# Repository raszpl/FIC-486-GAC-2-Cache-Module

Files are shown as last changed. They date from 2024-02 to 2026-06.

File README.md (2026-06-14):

# FIC-486-GAC-2 Cache Module reproduction
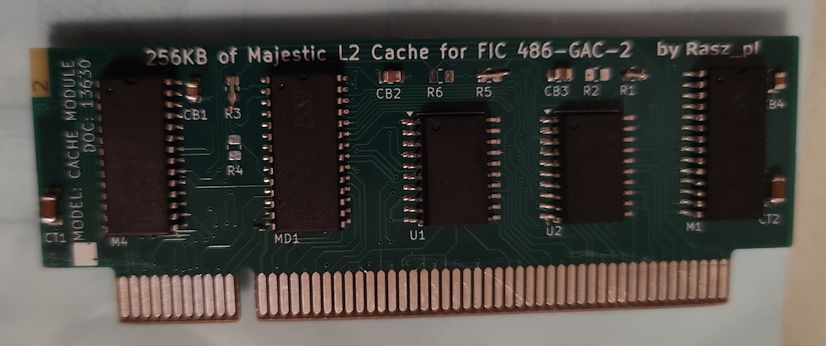
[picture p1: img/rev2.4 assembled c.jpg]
[](https://raw.githubusercontent.com/raszpl/FIC-486-GAC-2-Cache-Module/main/img/rev2.4%20assembled%20c.jpg)

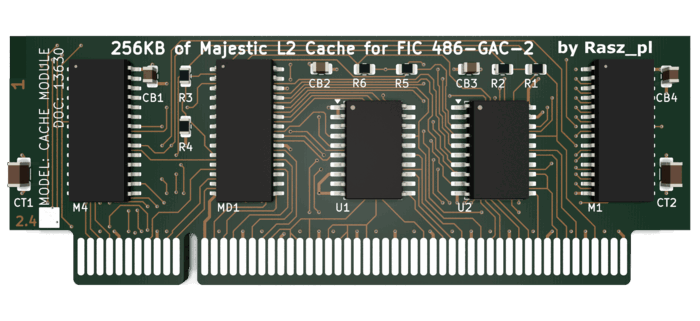
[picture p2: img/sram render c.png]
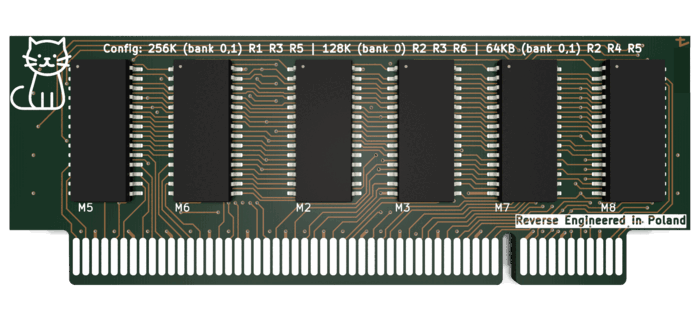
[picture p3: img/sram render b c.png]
[](https://raw.githubusercontent.com/raszpl/FIC-486-GAC-2-Cache-Module/main/img/sram%20render.png) [](https://raw.githubusercontent.com/raszpl/FIC-486-GAC-2-Cache-Module/main/img/sram%20render%20b.png)

Reverse Engineered non standard 256K L2 Cache Module for use in:

- AT&T GLOBALYST 510 = NCR 3228 = [FIC 486-GAC-2](https://theretroweb.com/motherboards/s/fic-486-gac-2)
- AT&T GLOBALYST 515 = NCR 3232 = [FIC 486-GAC-2](https://theretroweb.com/motherboards/s/fic-486-gac-2)

Potentially also:
- AT&T Globalyst 520 = NCR 3238 = [FIC 486-PAK-3](https://www.vogons.org/viewtopic.php?t=80951) needs confirmation
- AT&T Globalyst 530 = NCR 3338 = [FIC 486-PAK-3](https://www.vogons.org/viewtopic.php?t=80951) needs confirmation
- NCR 3231
- AT&T Globalyst 525 = NCR 3253

**Incompatible** platforms also reusing VLB slot for Cache:
- AT&T
  - [Globalyst 550 = NCR 3246](https://theretroweb.com/motherboards/s/atandt,-inc.-at-and-t,-inc.-globalyst-550-c) 
  - Globalyst 575 = NCR 3347 both use [517-0002811](https://raw.githubusercontent.com/raszpl/FIC-486-GAC-2-Cache-Module/refs/heads/main/not%20compatible%20proprietary%20vlb%20cache%20modules/ATT-Globalyst_550_575.jpg)
- Compaq
  - [ProLinea 4/66 (164560-001)](https://theretroweb.com/motherboards/s/compaq-prolinea-4-66)
  - [ProLinea MT/833CDS/850/850CDS/860CDS/866 (197023-001)](https://theretroweb.com/motherboards/s/compaq-prolinea-mt)
  - [Presario 700-900 series (171009-001)](https://theretroweb.com/motherboards/s/compaq-presario-700-900-series-486) all three use 128KB 197005-001 (aka 003454-001, 003670-001, 197050-001) [front](https://raw.githubusercontent.com/raszpl/FIC-486-GAC-2-Cache-Module/refs/heads/main/not%20compatible%20proprietary%20vlb%20cache%20modules/Compaq%20197005-001.jpg) [back](https://raw.githubusercontent.com/raszpl/FIC-486-GAC-2-Cache-Module/refs/heads/main/not%20compatible%20proprietary%20vlb%20cache%20modules/Compaq%20197005-001%20back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) [in slot](https://raw.githubusercontent.com/raszpl/FIC-486-GAC-2-Cache-Module/refs/heads/main/not%20compatible%20proprietary%20vlb%20cache%20modules/Compaq%20197005-001%20in%2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) 100% working DIY **[256KB/1MB Replacement](https://github.com/wichers/Compaq-Cache-Module-197005-001)** by [sander wichers](https://www.vogons.org/viewtopic.php?t=102242) inspired by this project :)
  - [Prosignia VS](https://www.digitaldungeon.be/digitaldungeon/computer/compaq/prosignia-vs_01/prosignia-vs_01.html) uses Sony CXK784862Q-33 based 256KB 194380-001 [front](/not%20compatible%20proprietary%20vlb%20cache%20modules/Compaq%20194380-001.jpg?raw=true) [back](https://raw.githubusercontent.com/raszpl/FIC-486-GAC-2-Cache-Module/refs/heads/main/not%20compatible%20proprietary%20vlb%20cache%20modules/Compaq%20194380-001%20back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)
  - [DESKPRO XE 486](https://theretroweb.com/motherboards/s/compaq-deskpro-xe-486) uses Sony CXK784862Q-33 based 256KB Kingston KTC-4358 [front](https://raw.githubusercontent.com/raszpl/FIC-486-GAC-2-Cache-Module/refs/heads/main/not%20compatible%20proprietary%20vlb%20cache%20modules/Kingston%20KTC-4358.jpg) [in slot](https://raw.githubusercontent.com/raszpl/FIC-486-GAC-2-Cache-Module/refs/heads/main/not%20compatible%20proprietary%20vlb%20cache%20modules/Kingston%20KTC-4358%20insi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). Maybe 194380-001 compatible?
  - [Deskpro/i Family 3](https://theretroweb.com/motherboards/s/compaq-deskpro-i-family-3-25i-rev-1-p-n-002) uses Intel A82485-33 based 64KB 141345-001 (002581)
  - [Deskpro/i Family 4](https://theretroweb.com/motherboards/s/compaq-deskpro-i-family-4-25is-rev-3-p-n-00) uses Intel A82485-33 based 64KB 141477-001 (002754) [front](https://raw.githubusercontent.com/raszpl/FIC-486-GAC-2-Cache-Module/refs/heads/main/not%20compatible%20proprietary%20vlb%20cache%20modules/Compaq%20002754-001.jpg) [back](https://raw.githubusercontent.com/raszpl/FIC-486-GAC-2-Cache-Module/refs/heads/main/not%20compatible%20proprietary%20vlb%20cache%20modules/Compaq%20002754-001%20back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)
- [HP Vectra VE 4](https://theretroweb.com/motherboards/s/hp-vectra-ve-4-xxx-d3501) uses 256KB HP D2465A/IDT 7MP6193 [front](https://raw.githubusercontent.com/raszpl/FIC-486-GAC-2-Cache-Module/refs/heads/main/not%20compatible%20proprietary%20vlb%20cache%20modules/HP%20Vectra%20VE%204%20256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) [back](https://raw.githubusercontent.com/raszpl/FIC-486-GAC-2-Cache-Module/refs/heads/main/not%20compatible%20proprietary%20vlb%20cache%20modules/HP%20Vectra%20VE%204%20256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)
- [HPE NetServer LC 5/166 (D4861AR)](https://theretroweb.com/motherboards/s/hp-netserver-lc) uses 256KB HP D3322A/IDT 7MP6152 (HP 0960-0899) [front](https://raw.githubusercontent.com/raszpl/FIC-486-GAC-2-Cache-Module/refs/heads/main/not%20compatible%20proprietary%20vlb%20cache%20modules/7MP6152.jpg)
- [Olivetti M4 454 S](https://theretroweb.com/motherboards/s/olivetti-m4-4x4) uses 128KB CYM9236 and 256KB CYM9237PB [front](https://raw.githubusercontent.com/raszpl/FIC-486-GAC-2-Cache-Module/refs/heads/main/not%20compatible%20proprietary%20vlb%20cache%20modules/CYM9236.jpg) [back](https://raw.githubusercontent.com/raszpl/FIC-486-GAC-2-Cache-Module/refs/heads/main/not%20compatible%20proprietary%20vlb%20cache%20modules/CYM9236%20back.jpg) [with slot](https://raw.githubusercontent.com/raszpl/FIC-486-GAC-2-Cache-Module/refs/heads/main/not%20compatible%20proprietary%20vlb%20cache%20modules/CYM9236%20and%20slot.jpg)
- [Siemens Nixdorf FD200 D882](https://theretroweb.com/motherboards/s/siemens-nixdorf-system-board-d882) uses 256KB CYM9252PB [front](https://raw.githubusercontent.com/raszpl/FIC-486-GAC-2-Cache-Module/refs/heads/main/not%20compatible%20proprietary%20vlb%20cache%20modules/Siemens%20Nixdorf%20FD200%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) [back](https://raw.githubusercontent.com/raszpl/FIC-486-GAC-2-Cache-Module/refs/heads/main/not%20compatible%20proprietary%20vlb%20cache%20modules/Siemens%20Nixdorf%20FD200%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) and unknown 128KB one.
## Resources
Pictures of the original "DOC: 13630" "ASSY: 008-0078204 A" Cache module:

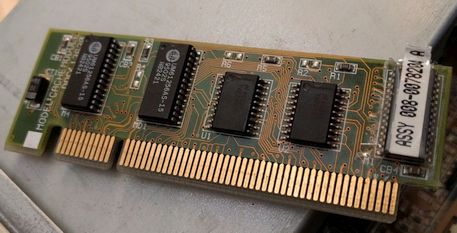
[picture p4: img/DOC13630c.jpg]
rev 2 [front ](https://raw.githubusercontent.com/raszpl/FIC-486-GAC-2-Cache-Module/main/img/DOC13630.jpg)

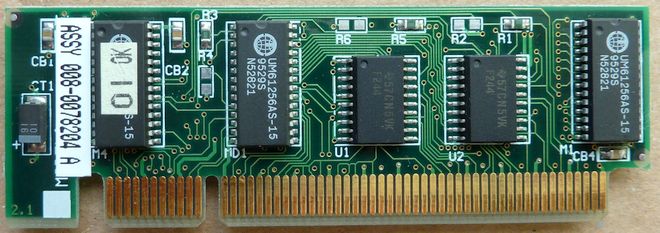
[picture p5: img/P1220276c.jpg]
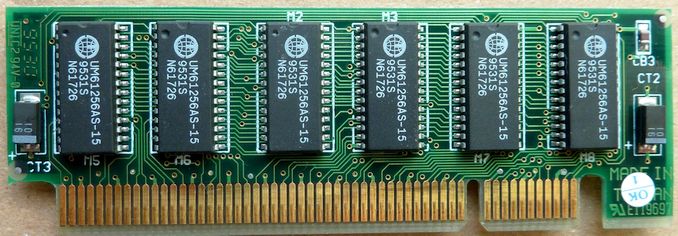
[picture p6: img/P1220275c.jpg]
rev 2.1 [front ](https://raw.githubusercontent.com/raszpl/FIC-486-GAC-2-Cache-Module/main/img/P1220276.JPG), [back ](https://raw.githubusercontent.com/raszpl/FIC-486-GAC-2-Cache-Module/main/img/P1220275.JPG)

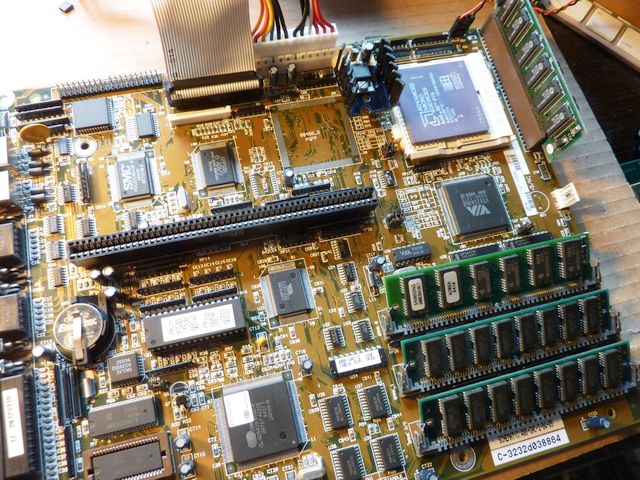
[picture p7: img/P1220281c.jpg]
[plugged into FIC 486-GAC-2](https://raw.githubusercontent.com/raszpl/FIC-486-GAC-2-Cache-Module/main/img/P1220281.JPG)

-----
Vogons [FIC 486-GAC-2 and proprietary cache module](https://www.vogons.org/viewtopic.php?f=46&t=94550) thread:
>majestyk: "FIC sold two different versions with different pinouts (and the same "VLB"-socket). Only the one in the pictures works on a 486-GAC2 and a few other FIC mainboards."

This project was only possible with help provided by majestyk - owner of this very rare Cache module, and RockstarRunner - FIC 486-GAC-2 owner looking for said Cache module. Huge thanks for taking time to capture high resolution pictures and validating progress with measurements.

[UMC UM61256A 32K x 8 Static RAM datasheet](/doc/UMC_UM61256A.pdf)

[VESA VLB slot pinout](/doc/VLB_pins.png) [VESA VLB slot dimensions](/doc/vlb-edge-conn.png)

## Status

100%. Manufactured and tested. Preliminary design took 8 days. Fixes after assembling first prototype 2 days.

## Progress report
4/19/2024: Rev 2.4 assembled by swapping components from Rev 2.2. CACHECHK screenshot.

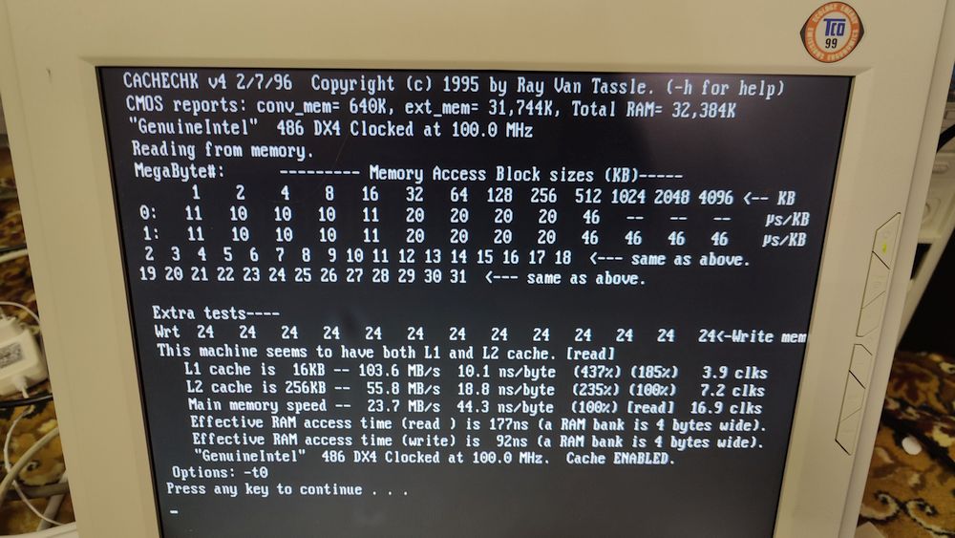
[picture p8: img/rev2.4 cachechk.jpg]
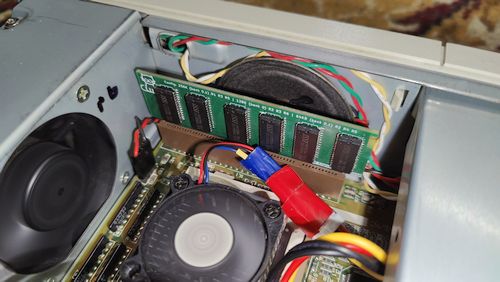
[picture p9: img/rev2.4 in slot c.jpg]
[](https://raw.githubusercontent.com/raszpl/FIC-486-GAC-2-Cache-Module/main/img/rev2.4%20assembled.jpg) [](https://raw.githubusercontent.com/raszpl/FIC-486-GAC-2-Cache-Module/main/img/rev2.4%20cachechk.jpg) [](https://raw.githubusercontent.com/raszpl/FIC-486-GAC-2-Cache-Module/main/img/rev2.4%20in%20slot.jpg)

4/15/2024: Rev 2.4 'Pcbs turned up! We have edge connectors this time 😆'

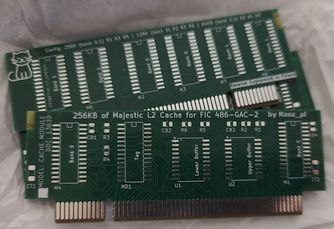
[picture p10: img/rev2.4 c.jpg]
[](https://raw.githubusercontent.com/raszpl/FIC-486-GAC-2-Cache-Module/main/img/rev2.4.jpg)

3/23/2024: [Final Rev 2.4](https://raw.githubusercontent.com/raszpl/FIC-486-GAC-2-Cache-Module/main/img/FIC%20486-GAC-2%20cache%20Final%20rev2.4.png). Reworked SRAM footprint for easier hand soldering, slightly optimized capacitor placement.

2/29/2024: [Final Rev 2.3](https://raw.githubusercontent.com/raszpl/FIC-486-GAC-2-Cache-Module/main/img/FIC%20486-GAC-2%20cache%20Final%20rev2.3.png). Slightly thicker tracks and silkscreen text, additional clearance work. Shrank from initial prototype, should be almost equal height of original. Height when inserted 26.3mm, height including slot 33.6mm. 

2/28/2024: Prototypes assembled after sanding off soldermask from edge slot contacts, didnt work at first try. Turns out I swapped few power/ground pins in the connector resulting in dead short. Great sleuthing by Miisalo uncovered this mishap, after cutting bad connections we have sucessfull boot.

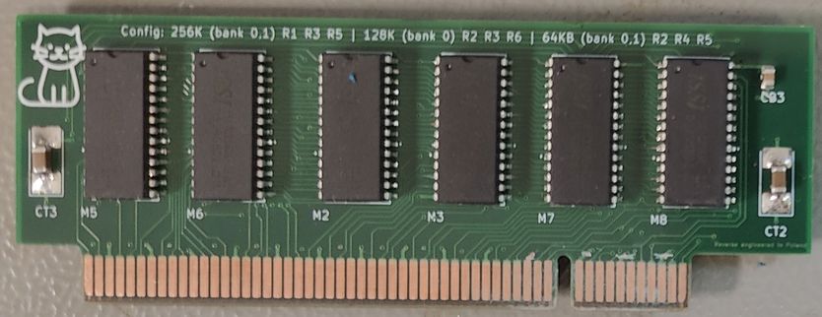
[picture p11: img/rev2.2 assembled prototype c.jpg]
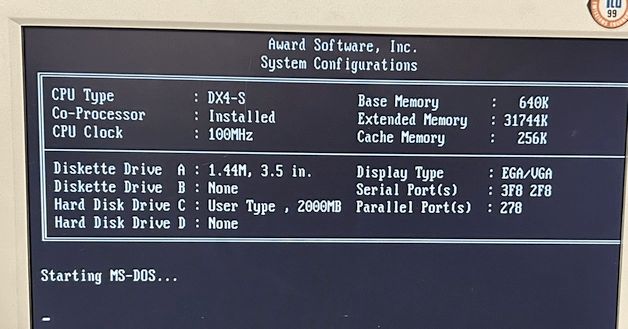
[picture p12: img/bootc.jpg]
[](https://raw.githubusercontent.com/raszpl/FIC-486-GAC-2-Cache-Module/main/img/rev2.2%20assembled%20prototype.jpg) [](https://raw.githubusercontent.com/raszpl/FIC-486-GAC-2-Cache-Module/main/img/boot.jpg)

2/27/2024: Prototypes arrived. Who can spot the problem?

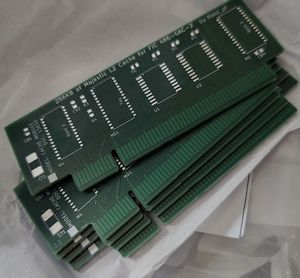
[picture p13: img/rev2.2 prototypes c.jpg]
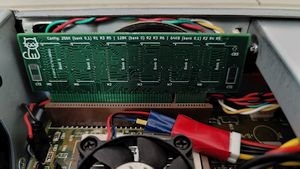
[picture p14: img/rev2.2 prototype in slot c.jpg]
[](https://raw.githubusercontent.com/raszpl/FIC-486-GAC-2-Cache-Module/main/img/rev2.2%20prototypes.jpg) [](https://raw.githubusercontent.com/raszpl/FIC-486-GAC-2-Cache-Module/main/img/rev2.2%20prototype%20in%20slot.jpg)

Will require some finessing with sandpaper to uncover edge slot pads :)

2/11/2024: [99% done](https://raw.githubusercontent.com/raszpl/FIC-486-GAC-2-Cache-Module/main/img/FIC%20486-GAC-2%20cache%20coast%20VIP%2099%25.png), ERC&DRC 0 errors 0 warnings. Footprints should be correct now. Gerbers sent for manufacturing.

2/8/2024: [95% there](https://raw.githubusercontent.com/raszpl/FIC-486-GAC-2-Cache-Module/main/img/FIC%20486-GAC-2%20cache%20coast%20VIP%2095%25.png), 0 errors, 7 Warnings. 5 connections missing, 11 guesses and assumptions on U1 U2 and some more on common lines.

2/6/2024: [90% there](https://raw.githubusercontent.com/raszpl/FIC-486-GAC-2-Cache-Module/main/img/FIC%20486-GAC-2%20cache%20coast%20VIP%2090%25.png), 0 errors 18 warnings. Just a couple tracks left.

2/5/2024: [80% there](https://raw.githubusercontent.com/raszpl/FIC-486-GAC-2-Cache-Module/main/img/FIC%20486-GAC-2%20cache%20coast%20VIP%2080%25.png), 0 drc errors, 62 violations. Still bad footprints and I havent gotten around to fixing power/ground pins. Whats left is figuring LS244 address buffering mapping, TAG ram address and output pins to edge mapping, WE/CE/OE mapping to edge.

2/4/2024: Very VIP, only about 50% there at the moment.

02/3/2024: Project start. Figuring out how to make edge connector footprint, searching for SOJ-28L footprint.

-----------------
# Work for hire
Interested in having a piece of hardware reverse engineered/cloned? Drop me an [email](https://github.com/raszpl).

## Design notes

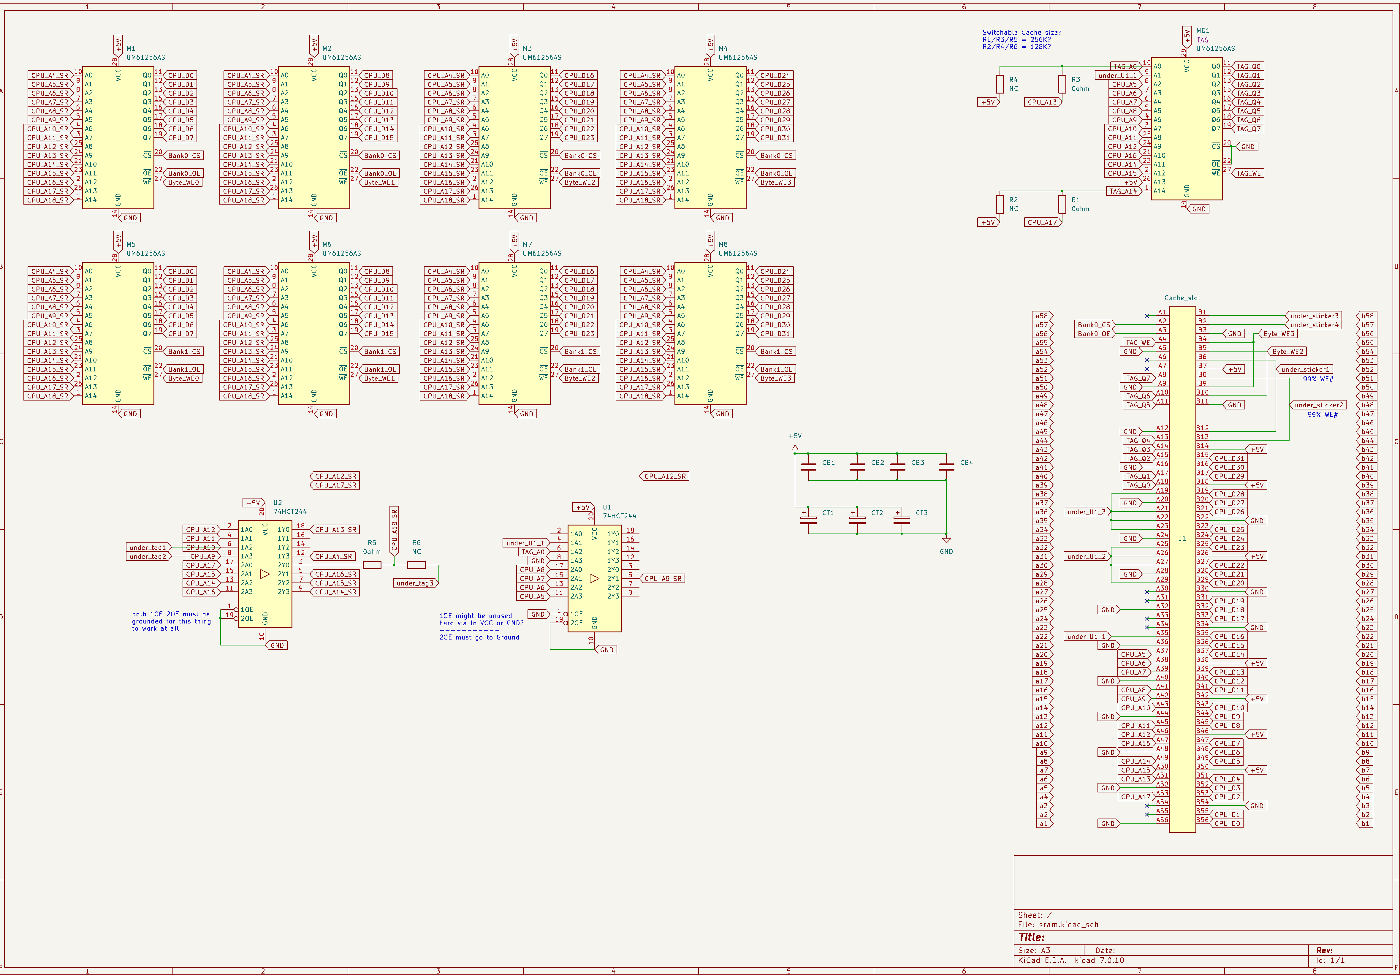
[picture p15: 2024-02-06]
img/FIC 486-GAC-2 cache coast VIP 90%.png

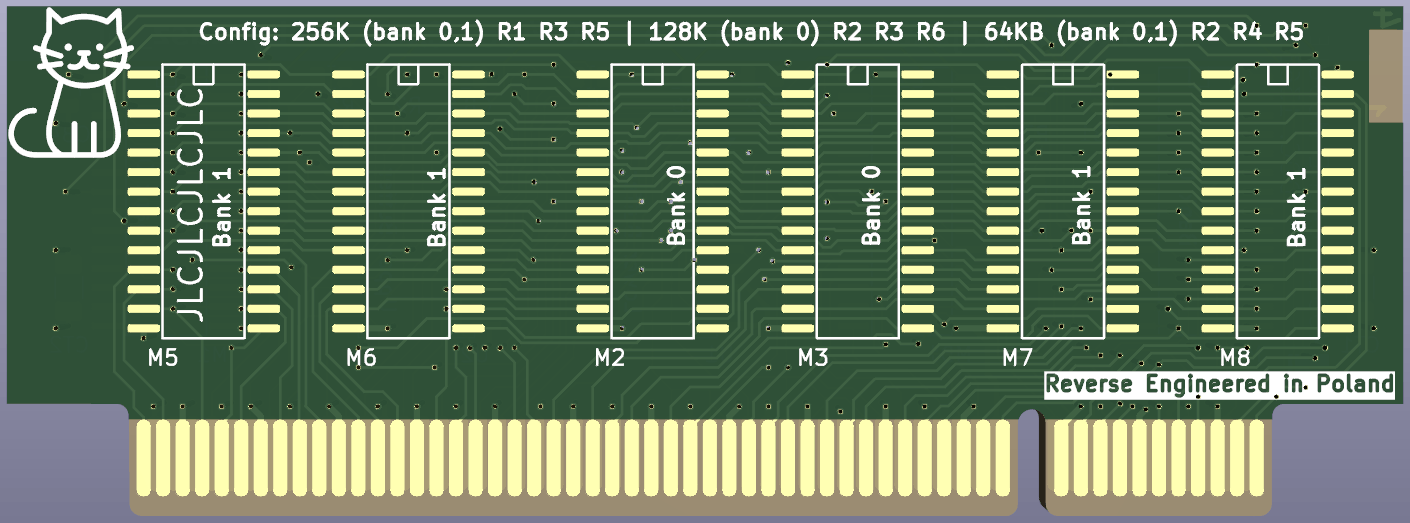
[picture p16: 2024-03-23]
img/back render.png

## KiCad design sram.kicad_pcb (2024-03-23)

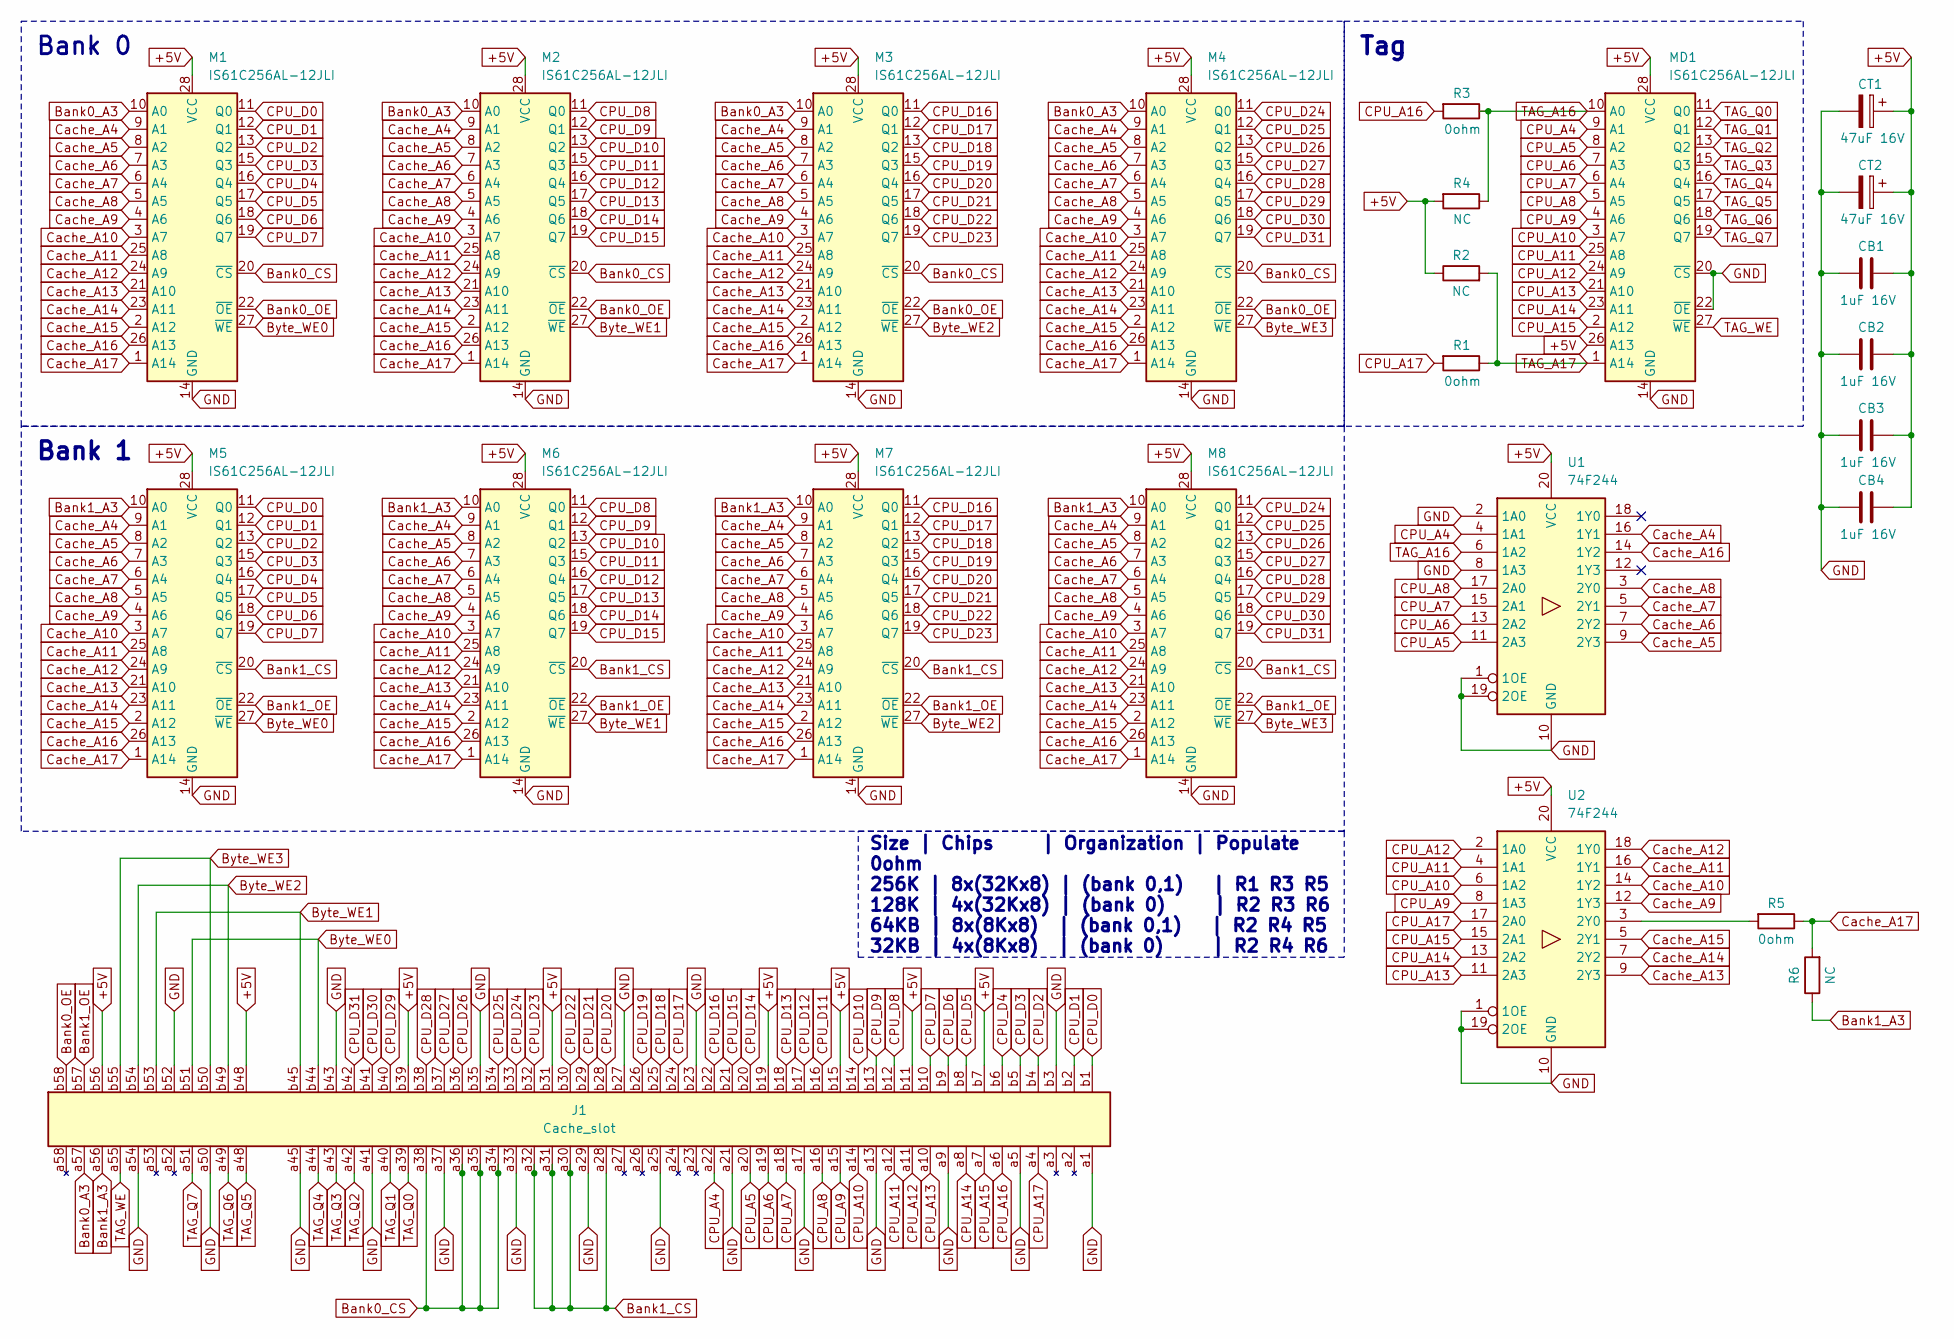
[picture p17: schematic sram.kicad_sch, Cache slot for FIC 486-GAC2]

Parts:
CB1, CB2, CB3, CB4: 1uF 16V; C_0805_2012Metric
CT1, CT2: 47uF 16V; C_1206_3216Metric_Pad1.33x1.80mm_HandSolder
J1: Cache_slot; Cache slot
M1, M2, M3, M4, M5, M6, M7, M8: IS61C256AL-12JLI; SOIC-28 very wide
MD1: IS61C256AL-12JLI; SOIC-28 very wide
R1, R3, R5: 0ohm; R_0805_2012Metric
R2, R4, R6: NC; R_0805_2012Metric
U1, U2: 74F244; SOIC-20W_7.5x12.8mm_P1.27mm

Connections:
+5V: CB1.1, CB2.1, CB3.1, CB4.1, CT1.1, CT2.1, J1.b7, J1.b11, J1.b15, J1.b19, J1.b31, J1.b39, J1.b48, J1.b56, M1.28 (VCC), M2.28 (VCC), M3.28 (VCC), M4.28 (VCC), M5.28 (VCC), M6.28 (VCC), M7.28 (VCC), M8.28 (VCC), MD1.26 (A13), MD1.28 (VCC), R2.1, R4.2, U1.20 (VCC), U2.20 (VCC)
Bank0_A3: J1.a57, M1.10 (A0), M2.10 (A0), M3.10 (A0), M4.10 (A0)
Bank0_CS: J1.a34, J1.a35, J1.a36, J1.a38, M1.20 (~CS), M2.20 (~CS), M3.20 (~CS), M4.20 (~CS)
Bank0_OE: J1.b58, M1.22 (~OE), M2.22 (~OE), M3.22 (~OE), M4.22 (~OE)
Bank1_A3: J1.a56, M5.10 (A0), M6.10 (A0), M7.10 (A0), M8.10 (A0), R6.1
Bank1_CS: J1.a28, J1.a30, J1.a31, J1.a32, M5.20 (~CS), M6.20 (~CS), M7.20 (~CS), M8.20 (~CS)
Bank1_OE: J1.b57, M5.22 (~OE), M6.22 (~OE), M7.22 (~OE), M8.22 (~OE)
Byte_WE0: J1.b44, J1.b51, M1.27 (~WE), M5.27 (~WE)
Byte_WE1: J1.b45, J1.b53, M2.27 (~WE), M6.27 (~WE)
Byte_WE2: J1.b49, J1.b54, M3.27 (~WE), M7.27 (~WE)
Byte_WE3: J1.b50, J1.b55, M4.27 (~WE), M8.27 (~WE)
CPU_A4: J1.a22, MD1.9 (A1), U1.4 (1A1)
CPU_A5: J1.a20, MD1.8 (A2), U1.11 (2A3)
CPU_A6: J1.a19, MD1.7 (A3), U1.13 (2A2)
CPU_A7: J1.a18, MD1.6 (A4), U1.15 (2A1)
CPU_A8: J1.a16, MD1.5 (A5), U1.17 (2A0)
CPU_A9: J1.a15, MD1.4 (A6), U2.8 (1A3)
CPU_A10: J1.a14, MD1.3 (A7), U2.6 (1A2)
CPU_A11: J1.a12, MD1.25 (A8), U2.4 (1A1)
CPU_A12: J1.a11, MD1.24 (A9), U2.2 (1A0)
CPU_A13: J1.a10, MD1.21 (A10), U2.11 (2A3)
CPU_A14: J1.a8, MD1.23 (A11), U2.13 (2A2)
CPU_A15: J1.a7, MD1.2 (A12), U2.15 (2A1)
CPU_A16: J1.a6, R3.2
CPU_A17: J1.a4, R1.2, U2.17 (2A0)
CPU_D0: J1.b1, M1.11 (Q0), M5.11 (Q0)
CPU_D1: J1.b2, M1.12 (Q1), M5.12 (Q1)
CPU_D2: J1.b4, M1.13 (Q2), M5.13 (Q2)
CPU_D3: J1.b5, M1.15 (Q3), M5.15 (Q3)
CPU_D4: J1.b6, M1.16 (Q4), M5.16 (Q4)
CPU_D5: J1.b8, M1.17 (Q5), M5.17 (Q5)
CPU_D6: J1.b9, M1.18 (Q6), M5.18 (Q6)
CPU_D7: J1.b10, M1.19 (Q7), M5.19 (Q7)
CPU_D8: J1.b12, M2.11 (Q0), M6.11 (Q0)
CPU_D9: J1.b13, M2.12 (Q1), M6.12 (Q1)
CPU_D10: J1.b14, M2.13 (Q2), M6.13 (Q2)
CPU_D11: J1.b16, M2.15 (Q3), M6.15 (Q3)
CPU_D12: J1.b17, M2.16 (Q4), M6.16 (Q4)
CPU_D13: J1.b18, M2.17 (Q5), M6.17 (Q5)
CPU_D14: J1.b20, M2.18 (Q6), M6.18 (Q6)
CPU_D15: J1.b21, M2.19 (Q7), M6.19 (Q7)
CPU_D16: J1.b22, M3.11 (Q0), M7.11 (Q0)
CPU_D17: J1.b24, M3.12 (Q1), M7.12 (Q1)
CPU_D18: J1.b25, M3.13 (Q2), M7.13 (Q2)
CPU_D19: J1.b26, M3.15 (Q3), M7.15 (Q3)
CPU_D20: J1.b28, M3.16 (Q4), M7.16 (Q4)
CPU_D21: J1.b29, M3.17 (Q5), M7.17 (Q5)
CPU_D22: J1.b30, M3.18 (Q6), M7.18 (Q6)
CPU_D23: J1.b32, M3.19 (Q7), M7.19 (Q7)
CPU_D24: J1.b33, M4.11 (Q0), M8.11 (Q0)
CPU_D25: J1.b34, M4.12 (Q1), M8.12 (Q1)
CPU_D26: J1.b36, M4.13 (Q2), M8.13 (Q2)
CPU_D27: J1.b37, M4.15 (Q3), M8.15 (Q3)
CPU_D28: J1.b38, M4.16 (Q4), M8.16 (Q4)
CPU_D29: J1.b40, M4.17 (Q5), M8.17 (Q5)
CPU_D30: J1.b41, M4.18 (Q6), M8.18 (Q6)
CPU_D31: J1.b42, M4.19 (Q7), M8.19 (Q7)
Cache_A4: M1.9 (A1), M2.9 (A1), M3.9 (A1), M4.9 (A1), M5.9 (A1), M6.9 (A1), M7.9 (A1), M8.9 (A1), U1.16 (1Y1)
Cache_A5: M1.8 (A2), M2.8 (A2), M3.8 (A2), M4.8 (A2), M5.8 (A2), M6.8 (A2), M7.8 (A2), M8.8 (A2), U1.9 (2Y3)
Cache_A6: M1.7 (A3), M2.7 (A3), M3.7 (A3), M4.7 (A3), M5.7 (A3), M6.7 (A3), M7.7 (A3), M8.7 (A3), U1.7 (2Y2)
Cache_A7: M1.6 (A4), M2.6 (A4), M3.6 (A4), M4.6 (A4), M5.6 (A4), M6.6 (A4), M7.6 (A4), M8.6 (A4), U1.5 (2Y1)
Cache_A8: M1.5 (A5), M2.5 (A5), M3.5 (A5), M4.5 (A5), M5.5 (A5), M6.5 (A5), M7.5 (A5), M8.5 (A5), U1.3 (2Y0)
Cache_A9: M1.4 (A6), M2.4 (A6), M3.4 (A6), M4.4 (A6), M5.4 (A6), M6.4 (A6), M7.4 (A6), M8.4 (A6), U2.12 (1Y3)
Cache_A10: M1.3 (A7), M2.3 (A7), M3.3 (A7), M4.3 (A7), M5.3 (A7), M6.3 (A7), M7.3 (A7), M8.3 (A7), U2.14 (1Y2)
Cache_A11: M1.25 (A8), M2.25 (A8), M3.25 (A8), M4.25 (A8), M5.25 (A8), M6.25 (A8), M7.25 (A8), M8.25 (A8), U2.16 (1Y1)
Cache_A12: M1.24 (A9), M2.24 (A9), M3.24 (A9), M4.24 (A9), M5.24 (A9), M6.24 (A9), M7.24 (A9), M8.24 (A9), U2.18 (1Y0)
Cache_A13: M1.21 (A10), M2.21 (A10), M3.21 (A10), M4.21 (A10), M5.21 (A10), M6.21 (A10), M7.21 (A10), M8.21 (A10), U2.9 (2Y3)
Cache_A14: M1.23 (A11), M2.23 (A11), M3.23 (A11), M4.23 (A11), M5.23 (A11), M6.23 (A11), M7.23 (A11), M8.23 (A11), U2.7 (2Y2)
Cache_A15: M1.2 (A12), M2.2 (A12), M3.2 (A12), M4.2 (A12), M5.2 (A12), M6.2 (A12), M7.2 (A12), M8.2 (A12), U2.5 (2Y1)
Cache_A16: M1.26 (A13), M2.26 (A13), M3.26 (A13), M4.26 (A13), M5.26 (A13), M6.26 (A13), M7.26 (A13), M8.26 (A13), U1.14 (1Y2)
Cache_A17: M1.1 (A14), M2.1 (A14), M3.1 (A14), M4.1 (A14), M5.1 (A14), M6.1 (A14), M7.1 (A14), M8.1 (A14), R5.1, R6.2
GND: CB1.2, CB2.2, CB3.2, CB4.2, CT1.2, CT2.2, J1.a1, J1.a5, J1.a9, J1.a13, J1.a17, J1.a21, J1.a25, J1.a29, J1.a33, J1.a37, J1.a41, J1.a45, J1.a50, J1.a54, J1.b3, J1.b23, J1.b27, J1.b35, J1.b43, J1.b52, M1.14 (GND), M2.14 (GND), M3.14 (GND), M4.14 (GND), M5.14 (GND), M6.14 (GND), M7.14 (GND), M8.14 (GND), MD1.14 (GND), MD1.20 (~CS), MD1.22 (~OE), U1.1 (1OE), U1.2 (1A0), U1.8 (1A3), U1.10 (GND), U1.19 (2OE), U2.1 (1OE), U2.10 (GND), U2.19 (2OE)
unnamed: R5.2, U2.3 (2Y0)
TAG_A16: MD1.10 (A0), R3.1, R4.1, U1.6 (1A2)
TAG_A17: MD1.1 (A14), R1.1, R2.2
TAG_Q0: J1.a39, MD1.11 (Q0)
TAG_Q1: J1.a40, MD1.12 (Q1)
TAG_Q2: J1.a42, MD1.13 (Q2)
TAG_Q3: J1.a43, MD1.15 (Q3)
TAG_Q4: J1.a44, MD1.16 (Q4)
TAG_Q5: J1.a48, MD1.17 (Q5)
TAG_Q6: J1.a49, MD1.18 (Q6)
TAG_Q7: J1.a51, MD1.19 (Q7)
TAG_WE: J1.a55, MD1.27 (~WE)

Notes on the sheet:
Bank 0
Tag
Size | Chips | Organization | Populate 0ohm 256K | 8x(32Kx8) | (bank 0,1) | R1 R3 R5 128K | 4x(32Kx8) | (bank 0) | R2 R3 R6 64KB | 8x(8Kx8) | (bank 0,1) | R2 R4 R5 32KB | 4x(8Kx8) | (bank 0) | R2 R4 R6
Bank 1

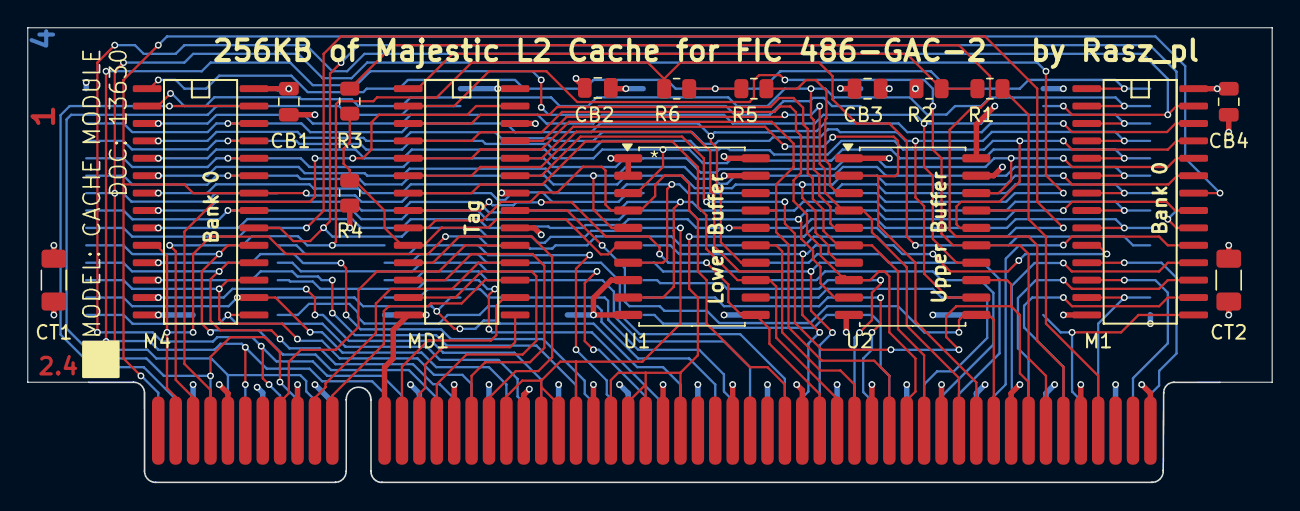
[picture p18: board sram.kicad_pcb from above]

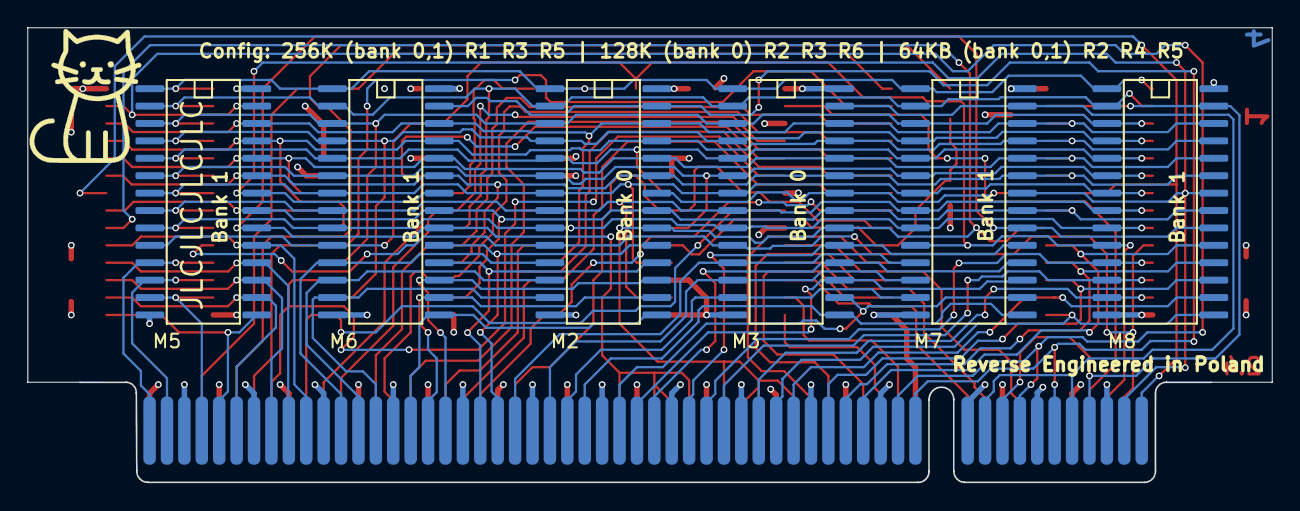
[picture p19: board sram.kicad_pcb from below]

Board: 4 copper layers, 90.8 x 33.2 mm, 24 parts (6 on the bottom side), 84 nets.

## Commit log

2024-02-05 First day of work
    [sram.kicad_pcb, sram.kicad_sch]
2024-02-05 3 errors, 76 warnings
    [sram.kicad_sch]
2024-02-06 0 drc errors, 62 violations
    [sram.kicad_sch]
2024-02-06 90% there, 0 errors 18 warnings. Just a couple tracks left.
    [sram.kicad_sch]
2024-02-08 95% there, 0 errors, 7 Warnings. 5 connections missing, 11 guesses and assumptions on U1 U2 and some more on common lines.
    [sram.kicad_sch]
2024-02-10 99% done, ERC DRC 0 errors 0 warnings
    [sram.kicad_pcb, sram.kicad_sch]
2024-02-11 are we done?
    [sram.kicad_pcb]
2024-02-11 config description correction
    [sram.kicad_pcb, sram.kicad_sch]
2024-02-29 Final Rev 2.3
    [sram.kicad_pcb, sram.kicad_sch]
2024-03-23 Final version 2.4
    [sram.kicad_pcb, sram.kicad_sch]
2024-10-08 Rename prototype in slot c.jpg to img/rev2.2 prototype in slot c.jpg
2024-10-08 Rename prototype in slot.jpg to img/rev2.2 prototype in slot.jpg
2024-10-08 Rename prototypes.jpg to img/rev2.2 prototypes.jpg
2024-10-08 Rename prototypes c.jpg to img/rev2.2 prototypes c.jpg
2024-10-08 Rename rev2.4 assembled prototype c.jpg to rev2.4 assembled c.jpg
2024-10-08 Rename rev2.4 assembled prototype.jpg to rev2.4 assembled.jpg
2024-10-08 Rename rev2.4 prototype in slot c.jpg to rev2.4 in slot c.jpg
2024-10-08 Rename rev2.4 prototype in slot.jpg to rev2.4 in slot.jpg
2024-10-08 Rename rev2.4 prototypes c.jpg to rev2.4 c.jpg
2024-10-08 Rename rev2.4 prototypes.jpg to rev2.4.jpg
2026-10-10 Update more incompatible boards reusing VLB
